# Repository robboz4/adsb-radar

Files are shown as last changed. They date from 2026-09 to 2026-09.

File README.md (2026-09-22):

# ADS-B Radar Display

A live aircraft radar scope for a small round LCD, built from ADS-B data. Runs
on either a Raspberry Pi Zero W or an XIAO ESP32-C3, both driving a 1.28"
GC9A01A round display (240×240, SPI).

## Features

- Live traffic from [adsb.lol](https://adsb.lol), with [adsb.fi](https://adsb.fi)
  as a fallback
- Bearing/distance radar scope centred on a fixed home location, with range
  rings and aircraft markers
- Sweep animation — a rotating arm reveals aircraft as it passes their bearing
- Phosphor-fade rendering — aircraft and labels fade out over time rather
  than disappearing instantly, mimicking an old CRT radar scope
- Two independent implementations sharing the same look and data source, so
  you can run this on whichever board you have on hand

## Hardware

| Platform | Files |
|---|---|
| Raspberry Pi Zero W  | `adsb_radar_core.py`, `adsb_radar_display.py` |
| XIAO ESP32-C3 | `WW11_RADAR-Final.ino` |

Both drive a 1.28" round GC9A01A SPI LCD (240×240).

### Raspberry Pi Zero W

- CircuitPython/displayio via Blinka, using `adafruit-circuitpython-gc9a01a`
  and `fourwire.FourWire`
- `adsb_radar_core.py` handles the adsb.lol/adsb.fi data and bearing/distance
  math; `adsb_radar_display.py` draws the scope
- Refresh is roughly 20 seconds/frame — a limitation of displayio's software
  rendering on the Zero, not the data source
- Run with the `radar` shell alias, or `python3 adsb_radar_display.py`

### XIAO ESP32-C3

- `WW11_RADAR-Final.ino`, built with Arduino_GFX, WiFiClientSecure,
  HTTPClient, and ArduinoJson
- Pin mapping (SDA/SCL labels instead of the Pi's CLK/DIN):

  | Signal | Pin          |
  |--------|--------------|
  | SDA    | D10 / GPIO10 |
  | SCL    | D8 / GPIO8   |
  | DC     | D4 / GPIO6   |
  | CS     | D5 / GPIO7   |
  | RST    | D6 / GPIO21  |

- **Built-in setup portal** — no need to hardcode WiFi credentials or a
  location in the sketch. If no WiFi is configured, the display shows the
  access point details instead of the radar scope. Connect to that access
  point at `192.168.4.1` from a phone, tablet, or computer and enter your
  WiFi network and your latitude/longitude from there.
- **Reset button** — a button on the back panel clears the saved WiFi and
  location settings. Hold it down for 3 seconds while powering the board on,
  then reconnect to `192.168.4.1` to reconfigure.

## Case

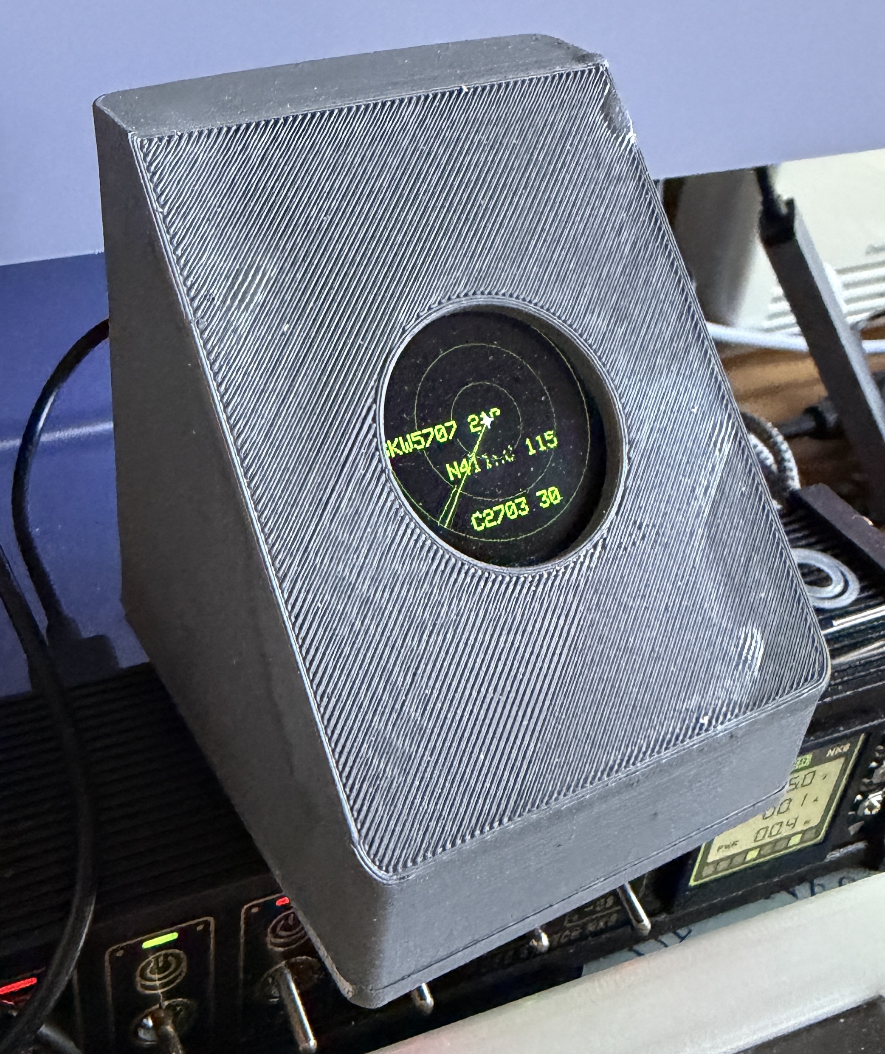
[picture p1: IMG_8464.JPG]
3D-printed case


- `RadarCase-Shell2.stl` and `RadarCase-RearCover.stl` are a 3D-printable
  enclosure sized for the ESP32-C3 build: sloped display face, corner mounting
  bosses for M3 heat-set inserts, and a 32 mm through-hole with internal
  guide posts that the display slides into from the top
- The rear cover includes a cutout for the reset button used to clear WiFi/
  location settings
- A matching Raspberry Pi enclosure hasn't been designed yet

## Configuration

- **ESP32-C3:** no code editing needed — WiFi and location are set through
  the `192.168.4.1` setup portal described above.
- **Raspberry Pi:** set your location directly in `adsb_radar_core.py`:

  ```python
  HOME_LAT = 0.00
  HOME_LON = 0.00cd 
  
  ```

## Roadmap

- Traffic filtering by commercial / private / military category
- A 3D-printable case for the Raspberry Pi build

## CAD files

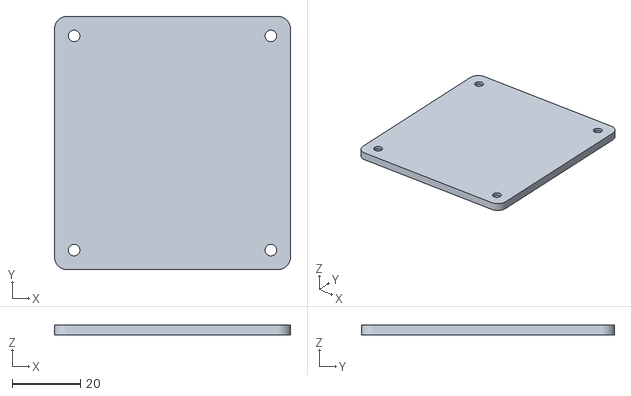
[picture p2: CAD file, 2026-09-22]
RadarCase-RearCover.stl
69.2 x 74.3 x 3.00

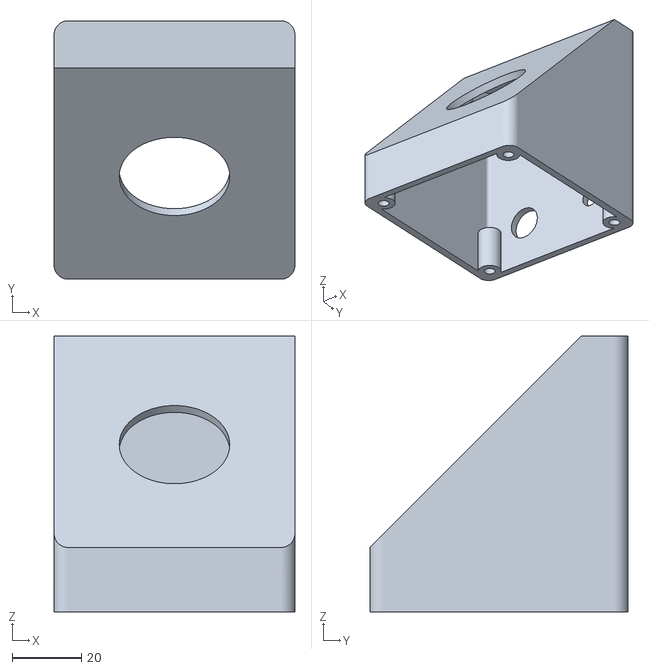
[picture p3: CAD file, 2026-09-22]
RadarCase-Shell2.stl
69.7 x 74.8 x 79.9

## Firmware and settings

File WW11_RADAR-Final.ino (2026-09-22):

// ============================================================
// WW-II Phosphor Radar - XIAO ESP32-C3 + GC9A01 Round LCD
// ============================================================
// Authentic WWII PPI radar simulation with captive portal
// configuration -- no recompile needed to change settings.
//
// FIRST TIME SETUP:
//   1. Power on the device
//   2. Connect your phone/laptop to WiFi network "RadarSetup"
//   3. A config page will open automatically (captive portal)
//   4. Enter your WiFi credentials, latitude, longitude, radius
//   5. Hit Save -- device reboots and starts radar mode
//
// RECONFIGURE:
//   Hold external button on D7 (GPIO20) for 3 seconds at
//   power-on to reset settings and re-enter setup mode
//
// Wiring (XIAO ESP32-C3):
//   Display VCC → 3.3V
//   Display GND → GND
//   Display SCL → D8  (GPIO8)
//   Display SDA → D10 (GPIO10)
//   Display DC  → D4  (GPIO6)
//   Display CS  → D5  (GPIO7)
//   Display RST → D6  (GPIO21)
//   Reset button → D7 (GPIO20) to GND
//
// Libraries required:
//   - GFX Library for Arduino (moononournation)
//   - WiFiManager (tzapu)
//   - ArduinoJson (Benoit Blanchon)
// ============================================================

#include <Arduino_GFX_Library.h>
#include <WiFi.h>
#include <WiFiClientSecure.h>
#include <WiFiManager.h>
#include <HTTPClient.h>
#include <ArduinoJson.h>
#include <Preferences.h>
#include <math.h>

// ============================================================
// DISPLAY PINS (XIAO ESP32-C3)
// ============================================================
#define TFT_CS   7    // D5
#define TFT_DC   6    // D4
#define TFT_RST  21   // D6
#define TFT_MOSI 10   // D10
#define TFT_SCLK 8    // D8

// External reset button (momentary switch to GND)
#define BOOT_PIN 20   // D7

// ============================================================
// COLOURS (RGB565)
// ============================================================
#define COLOR_BG      0x0020  // near-black green background
#define COLOR_RING    0x02A0  // static ring green (never fades)
#define COLOR_CENTER  0xFFFF  // white center marker (never fades)
#define COLOR_SWEEP   0x47E6  // bright sweep arm green
#define BLACK         0x0000
#define RED           0xF800
#define WHITE         0xFFFF

// Phosphor brightness steps: full bright → dim → background
// 9 steps for smooth staircase decay over FADE_MS
const uint16_t PHOSPHOR[] = {
    0x07E0,   // step 0: full bright green (100%)
    0x06E0,   // step 1: ~87%
    0x05E0,   // step 2: ~75%
    0x04E0,   // step 3: ~62%
    0x03E0,   // step 4: ~50%
    0x02E0,   // step 5: ~37%
    0x01E0,   // step 6: ~25%
    0x00E0,   // step 7: very dim
    0x0020    // step 8: background (gone)
};
const int PHOSPHOR_STEPS = 9;

// ============================================================
// RADAR GEOMETRY
// ============================================================
#define SCREEN_W   240
#define SCREEN_H   240
#define CENTER_X   120
#define CENTER_Y   120
#define MAX_RADIUS 108  // outermost ring radius in pixels
#define RING_COUNT 3    // number of range rings
#define MAX_AC     30   // max aircraft to track
#define DOT_SIZE   3    // overlap marker dot radius

// ============================================================
// CONFIGURATION (loaded from flash at startup)
// ============================================================
float        HOME_LAT  = 38.80579;   // default fallback
float        HOME_LON  = -121.11277; // default fallback
int          RADIUS_NM = 10;         // default fallback

const unsigned long SWEEP_MS = 2000; // sweep arm duration (ms)
const unsigned long FADE_MS  = 8000; // total fade duration (ms)

// ============================================================
// AIRCRAFT DATA STRUCTURE
// ============================================================
struct Aircraft {
    float bearing_deg;  // bearing from home (0=North, clockwise)
    int   x, y;         // screen pixel coordinates
    int   alt_ft;       // altitude in feet
    char  callsign[10]; // callsign or tail number
};

Aircraft ac_list[MAX_AC];
int      ac_count = 0;

// Label bounding boxes for overlap detection
struct LabelBox {
    int x, y, w, h;
};
LabelBox drawn_boxes[MAX_AC];
int      box_count = 0;

// ============================================================
// GFX + PREFERENCES
// ============================================================
Arduino_DataBus *bus = new Arduino_ESP32SPI(
    TFT_DC, TFT_CS, TFT_SCLK, TFT_MOSI, GFX_NOT_DEFINED
);
Arduino_GFX *gfx = new Arduino_GC9A01(bus, TFT_RST, 0, true);

Preferences prefs;

// ============================================================
// MATH HELPERS
// ============================================================

// Great-circle bearing from point 1 to point 2
// Returns 0-360 degrees (0=North, clockwise)
float calc_bearing(float lat1, float lon1, float lat2, float lon2) {
    float phi1 = radians(lat1), phi2 = radians(lat2);
    float dl   = radians(lon2 - lon1);
    float y    = sin(dl) * cos(phi2);
    float x    = cos(phi1)*sin(phi2) - sin(phi1)*cos(phi2)*cos(dl);
    float brng = fmod(degrees(atan2(y, x)) + 360.0, 360.0);
    if (brng >= 360.0f) brng = 0.0f;
    return brng;
}

// Haversine distance between two points in nautical miles
float calc_distance_nm(float lat1, float lon1, float lat2, float lon2) {
    const float R = 3440.065;
    float dphi = radians(lat2 - lat1);
    float dl   = radians(lon2 - lon1);
    float phi1 = radians(lat1), phi2 = radians(lat2);
    float a = sin(dphi/2)*sin(dphi/2) +
              cos(phi1)*cos(phi2)*sin(dl/2)*sin(dl/2);
    return R * 2 * atan2(sqrt(a), sqrt(1-a));
}

// Convert bearing + distance to screen x,y pixel coordinates
void polar_to_xy(float brng, float dist_nm, int &x, int &y) {
    float scale = min(dist_nm / (float)RADIUS_NM, 1.0f);
    float r     = scale * MAX_RADIUS;
    float a     = radians(brng);
    x = CENTER_X + (int)(r * sin(a));
    y = CENTER_Y - (int)(r * cos(a));
}

// Sort aircraft by bearing (insertion sort)
void sort_by_bearing() {
    for (int i = 1; i < ac_count; i++) {
        Aircraft key = ac_list[i];
        int j = i - 1;
        while (j >= 0 && ac_list[j].bearing_deg > key.bearing_deg) {
            ac_list[j+1] = ac_list[j];
            j--;
        }
        ac_list[j+1] = key;
    }
}

// ============================================================
// OVERLAP DETECTION
// Check if a proposed label rectangle overlaps any already
// drawn label. Returns true if overlap detected.
// ============================================================
bool overlaps_existing(int lx, int ly, int lw, int lh) {
    for (int i = 0; i < box_count; i++) {
        if (lx < drawn_boxes[i].x + drawn_boxes[i].w &&
            lx + lw > drawn_boxes[i].x &&
            ly < drawn_boxes[i].y + drawn_boxes[i].h &&
            ly + lh > drawn_boxes[i].y) {
            return true;
        }
    }
    return false;
}

// ============================================================
// DRAWING FUNCTIONS
// ============================================================

// Draw center crosshair marker (your location)
void draw_center_marker() {
    gfx->fillCircle(CENTER_X, CENTER_Y, 3, COLOR_CENTER);
    gfx->drawLine(CENTER_X-6, CENTER_Y, CENTER_X+6, CENTER_Y, COLOR_CENTER);
    gfx->drawLine(CENTER_X, CENTER_Y-6, CENTER_X, CENTER_Y+6, COLOR_CENTER);
}

// Draw permanent static background -- rings never fade,
// simulating etched glass overlay on real WWII radar scopes
void draw_static_scene() {
    gfx->fillScreen(COLOR_BG);
    for (int i = 1; i <= RING_COUNT; i++) {
        int r = MAX_RADIUS * i / RING_COUNT;
        gfx->drawCircle(CENTER_X, CENTER_Y, r, COLOR_RING);
    }
    gfx->drawCircle(CENTER_X, CENTER_Y, MAX_RADIUS, COLOR_RING);
    draw_center_marker();
}

// Draw one aircraft label at a given phosphor brightness.
// If label would overlap an existing one, draw a small dot
// instead so the aircraft position is still visible.
void draw_one_aircraft(int idx, uint16_t colour) {
    Aircraft &ac = ac_list[idx];

    int  alt_k = (int)(ac.alt_ft / 100);
    char label[16];
    snprintf(label, sizeof(label), "%s %d", ac.callsign, alt_k);

    int label_len = strlen(label);
    int label_w   = label_len * 12;  // 12px per char at textSize 2
    int label_h   = 16;              // 16px tall at textSize 2

    // Position label to right of dot by default,
    // flip left if it would overflow right edge
    int lx = ac.x + 6;
    if (lx + label_w > SCREEN_W - 2) lx = ac.x - label_w - 6;
    if (lx < 2) lx = 2;

    int ly = ac.y - 4;
    if (ly < label_h)                 ly = ac.y + 6;
    if (ly + label_h > SCREEN_H - 2) ly = SCREEN_H - label_h - 2;

    if (overlaps_existing(lx, ly, label_w, label_h)) {
        // Overlap detected -- draw small dot instead of label
        gfx->fillCircle(ac.x, ac.y, DOT_SIZE, colour);
        Serial.printf("  [overlap] %s -- dot only\n", ac.callsign);
    } else {
        // No overlap -- record bounding box and draw full label
        drawn_boxes[box_count++] = {lx, ly, label_w, label_h};
        gfx->fillRect(lx, ly, label_w + 4, label_h, COLOR_BG);
        gfx->setTextWrap(false);
        gfx->setTextSize(2);
        int cx = lx;
        for (int i = 0; i < label_len; i++) {
            gfx->drawChar(cx, ly, (unsigned char)label[i], colour, COLOR_BG);
            cx += 12;
        }
    }
}

// Draw all aircraft at a given brightness level
void draw_all_aircraft(uint16_t colour) {
    box_count = 0;  // reset overlap tracking for this redraw
    for (int i = 0; i < ac_count; i++) {
        draw_one_aircraft(i, colour);
    }
}

// Draw sweep arm line from center to edge at given angle
void draw_sweep_arm(float angle_deg, uint16_t colour) {
    float a  = radians(angle_deg);
    int   x2 = CENTER_X + (int)(MAX_RADIUS * sin(a));
    int   y2 = CENTER_Y - (int)(MAX_RADIUS * cos(a));
    gfx->drawLine(CENTER_X, CENTER_Y, x2, y2, colour);
}

// Draw status line at top of screen
void draw_status(int count, bool wifi_ok) {
    gfx->fillRect(0, 0, SCREEN_W, 14, COLOR_BG);
    gfx->setTextSize(1);
    gfx->setTextColor(PHOSPHOR[0], COLOR_BG);
    gfx->setCursor(10, 3);
    if (!wifi_ok) {
        gfx->print("No WiFi");
    } else {
        gfx->print(count);
        gfx->print(" ac  ");
        gfx->print(RADIUS_NM);
        gfx->print("nm");
    }
}

// Display a centered message -- used during WiFi setup
void show_message(const char* line1, const char* line2 = nullptr,
                  uint16_t colour = WHITE) {
    gfx->fillScreen(BLACK);
    for (int i = 1; i <= RING_COUNT; i++) {
        int r = MAX_RADIUS * i / RING_COUNT;
        gfx->drawCircle(CENTER_X, CENTER_Y, r, 0x0060);
    }
    gfx->setTextWrap(true);
    gfx->setTextSize(1);
    gfx->setTextColor(colour, BLACK);
    if (line2 == nullptr) {
        gfx->setCursor(10, 115);
        gfx->print(line1);
    } else {
        gfx->setCursor(10, 105);
        gfx->print(line1);
        gfx->setCursor(10, 120);
        gfx->print(line2);
    }
}

// ============================================================
// RADAR SWEEP ANIMATION
// Arm rotates 0->360 over SWEEP_MS revealing aircraft as it
// passes their bearing. Uses surgical erase (previous arm line
// only) to prevent flicker on already-revealed labels.
// ============================================================
void radar_sweep() {
    sort_by_bearing();

    int next_ac = 0;
    box_count = 0;  // reset overlap tracking for new sweep
    unsigned long sweep_start = millis();
    const int STEPS = 180;  // 2 degrees per step

    // Full clean wipe before sweep -- clears previous cycle's
    // faded aircraft. Double fillScreen ensures complete clear.
    gfx->fillScreen(COLOR_BG);
    gfx->fillScreen(COLOR_BG);
    for (int i = 1; i <= RING_COUNT; i++) {
        int r = MAX_RADIUS * i / RING_COUNT;
        gfx->drawCircle(CENTER_X, CENTER_Y, r, COLOR_RING);
    }
    gfx->drawCircle(CENTER_X, CENTER_Y, MAX_RADIUS, COLOR_RING);
    draw_center_marker();

    float prev_angle = -1;

    for (int step = 0; step <= STEPS; step++) {
        float angle = 360.0f * step / STEPS;

        // Surgical erase: repaint previous arm line with background,
        // then restore ring pixels the arm erased
        if (prev_angle >= 0) {
            draw_sweep_arm(prev_angle, COLOR_BG);
            for (int i = 1; i <= RING_COUNT; i++) {
                int r = MAX_RADIUS * i / RING_COUNT;
                float pa = radians(prev_angle);
                int rx = CENTER_X + (int)(r * sin(pa));
                int ry = CENTER_Y - (int)(r * cos(pa));
                gfx->drawPixel(rx, ry, COLOR_RING);
            }
            float pa = radians(prev_angle);
            int rx = CENTER_X + (int)(MAX_RADIUS * sin(pa));
            int ry = CENTER_Y - (int)(MAX_RADIUS * cos(pa));
            gfx->drawPixel(rx, ry, COLOR_RING);
        }

        // Reveal aircraft whose bearing the sweep arm has reached.
        // angle > 0.5 guard prevents reveals before arm has moved.
        while (next_ac < ac_count &&
               ac_list[next_ac].bearing_deg <= angle &&
               angle > 0.5f) {
            Serial.printf("Revealing %s at sweep angle=%.1f brng=%.1f\n",
                ac_list[next_ac].callsign, angle,
                ac_list[next_ac].bearing_deg);
            draw_one_aircraft(next_ac, PHOSPHOR[0]);
            next_ac++;
        }

        // Draw sweep arm at current angle
        draw_sweep_arm(angle, COLOR_SWEEP);
        draw_center_marker();
        prev_angle = angle;

        // Pace sweep to SWEEP_MS total duration
        unsigned long elapsed  = millis() - sweep_start;
        unsigned long expected = (unsigned long)(SWEEP_MS * step / STEPS);
        if (expected > elapsed) delay(expected - elapsed);
    }

    // Clean up: erase final arm, restore outer ring, reveal
    // any remaining aircraft (edge case: bearing near 360)
    draw_sweep_arm(360.0f, COLOR_BG);
    gfx->drawCircle(CENTER_X, CENTER_Y, MAX_RADIUS, COLOR_RING);
    draw_center_marker();
    while (next_ac < ac_count) {
        draw_one_aircraft(next_ac, PHOSPHOR[0]);
        next_ac++;
    }
}

// ============================================================
// PHOSPHOR FADE
// Steps through 9 brightness levels over FADE_MS total.
// Each step: wipe screen, redraw rings (permanent), redraw
// aircraft at next dimmer colour level.
// Rings and center marker never fade -- etched glass effect.
// ============================================================
void phosphor_fade() {
    unsigned long step_ms = FADE_MS / (PHOSPHOR_STEPS - 1);
    // 8000ms / 8 steps = 1000ms per step

    for (int step = 1; step < PHOSPHOR_STEPS; step++) {
        delay(step_ms);

        gfx->fillScreen(COLOR_BG);

        // Rings and center always redrawn solid -- never fade
        for (int i = 1; i <= RING_COUNT; i++) {
            int r = MAX_RADIUS * i / RING_COUNT;
            gfx->drawCircle(CENTER_X, CENTER_Y, r, COLOR_RING);
        }
        gfx->drawCircle(CENTER_X, CENTER_Y, MAX_RADIUS, COLOR_RING);
        draw_center_marker();

        // Redraw aircraft at current fade level
        // Skip last step -- background colour, nothing to draw
        if (step < PHOSPHOR_STEPS - 1) {
            draw_all_aircraft(PHOSPHOR[step]);
        }

        draw_status(ac_count, WiFi.status() == WL_CONNECTED);
    }
}

// ============================================================
// ADS-B DATA FETCH
// Tries adsb.lol first, falls back to adsb.fi on failure.
// Uses getString() to avoid IncompleteInput parse errors.
// ============================================================
int fetch_aircraft() {
    if (WiFi.status() != WL_CONNECTED) return -1;

    const char* api_urls[2] = {
        "https://api.adsb.lol/v2/point/%.4f/%.4f/%d",
        "https://opendata.adsb.fi/api/v2/point/%.4f/%.4f/%d"
    };

    String payload  = "";
    bool   got_data = false;

    for (int u = 0; u < 2 && !got_data; u++) {
        char url[128];
        snprintf(url, sizeof(url), api_urls[u],
                 HOME_LAT, HOME_LON, RADIUS_NM);
        Serial.printf("Trying: %s\n", url);

        WiFiClientSecure client;
        client.setInsecure();
        HTTPClient http;
        http.begin(client, url);
        http.setTimeout(8000);
        int httpCode = http.GET();

        if (httpCode == 200) {
            payload  = http.getString();
            got_data = true;
            Serial.println("Fetch OK");
        } else {
            Serial.printf("HTTP %d, trying next...\n", httpCode);
        }
        http.end();
    }

    if (!got_data) return -1;

    // Filter to only fields we need (saves RAM)
    DynamicJsonDocument filter(200);
    JsonObject ac_filter = filter["ac"].createNestedObject();
    ac_filter["lat"]      = true;
    ac_filter["lon"]      = true;
    ac_filter["alt_baro"] = true;
    ac_filter["flight"]   = true;
    ac_filter["hex"]      = true;

    DynamicJsonDocument doc(24576);  // 24KB buffer
    DeserializationError err = deserializeJson(doc, payload,
        DeserializationOption::Filter(filter));

    if (err) {
        Serial.printf("JSON error: %s\n", err.c_str());
        return -1;
    }

    JsonArray aircraft = doc["ac"];
    ac_count = 0;

    for (JsonObject ac : aircraft) {
        if (ac_count >= MAX_AC) break;

        float ac_lat = ac["lat"] | -999.0f;
        float ac_lon = ac["lon"] | -999.0f;
        if (ac_lat == -999.0f || ac_lon == -999.0f) continue;

        float dist = calc_distance_nm(HOME_LAT, HOME_LON, ac_lat, ac_lon);
        if (dist > RADIUS_NM) continue;

        int alt_ft = 0;
        if (ac["alt_baro"].is<int>()) alt_ft = ac["alt_baro"].as<int>();

        const char* cs_raw = ac["flight"] | ac["hex"] | "?";
        memset(ac_list[ac_count].callsign, 0,
               sizeof(ac_list[0].callsign));
        strncpy(ac_list[ac_count].callsign, cs_raw,
                sizeof(ac_list[0].callsign) - 1);

        // Trim trailing whitespace from callsign
        for (int i = strlen(ac_list[ac_count].callsign)-1;
             i >= 0 && (ac_list[ac_count].callsign[i] == ' '  ||
                        ac_list[ac_count].callsign[i] == '\t' ||
                        ac_list[ac_count].callsign[i] == '\r' ||
                        ac_list[ac_count].callsign[i] == '\n'); i--)
            ac_list[ac_count].callsign[i] = '\0';

        ac_list[ac_count].alt_ft      = alt_ft;
        ac_list[ac_count].bearing_deg = calc_bearing(
            HOME_LAT, HOME_LON, ac_lat, ac_lon);
        polar_to_xy(ac_list[ac_count].bearing_deg, dist,
                    ac_list[ac_count].x, ac_list[ac_count].y);

        Serial.printf("  [%d] %s alt=%d brng=%.0f dist=%.1fnm\n",
            ac_count, ac_list[ac_count].callsign,
            alt_ft, ac_list[ac_count].bearing_deg, dist);

        ac_count++;
    }

    return 0;
}

// ============================================================
// SETTINGS: SAVE / LOAD / RESET (ESP32 flash via Preferences)
// ============================================================
void save_settings(float lat, float lon, int nm) {
    prefs.begin("radar", false);
    prefs.putFloat("lat", lat);
    prefs.putFloat("lon", lon);
    prefs.putInt("nm",  nm);
    prefs.putBool("configured", true);
    prefs.end();
    Serial.printf("Settings saved: lat=%.5f lon=%.5f nm=%d\n",
                  lat, lon, nm);
}

bool load_settings() {
    prefs.begin("radar", true);
    bool configured = prefs.getBool("configured", false);
    if (configured) {
        HOME_LAT  = prefs.getFloat("lat", HOME_LAT);
        HOME_LON  = prefs.getFloat("lon", HOME_LON);
        RADIUS_NM = prefs.getInt("nm",   RADIUS_NM);
    }
    prefs.end();
    Serial.printf("Settings loaded: lat=%.5f lon=%.5f nm=%d\n",
                  HOME_LAT, HOME_LON, RADIUS_NM);
    return configured;
}

void reset_settings() {
    prefs.begin("radar", false);
    prefs.clear();
    prefs.end();
    Serial.println("Settings cleared.");
}
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
void loop() {
    Serial.println("\n--- New cycle ---");

    int result = fetch_aircraft();
    if (result != 0) {
        Serial.println("Fetch failed, using last known data.");
    }

    radar_sweep();
    draw_status(ac_count, WiFi.status() == WL_CONNECTED);
    phosphor_fade();
}

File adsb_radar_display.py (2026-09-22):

"""
ADS-B Aircraft Radar for the 1.28" round GC9A01A LCD on Raspberry Pi.

Draws a radar-scope view: your location at the center, range rings,
and aircraft positioned by real-time bearing/distance. Each aircraft
is shown as a single text label (an asterisk marker + callsign +
altitude) -- marker and text are baked into one Label object so they
always appear together, with no possibility of one updating before
the other during a slow refresh. Refreshes periodically from adsb.lol.

Design note: the background, range rings, and center marker are drawn
directly into ONE bitmap that is fully repainted (cleared + redrawn)
every cycle, and each refresh cycle first wipes to a blank scene before
drawing the new one. This avoids ghosting/trails that occur when many
small separate sprites or labels are added/removed individually --
Blinka's displayio dirty-region tracking can miss repainting the exact
old footprint of a removed sprite. A full wipe + full repaint guarantees
every pixel is touched and no stale frame is ever partially visible.

Run with: python3 adsb_radar_display.py
Stop with: Ctrl+C
"""

import time
import math
import board
import busio
import displayio
import digitalio
import terminalio
import fourwire
from adafruit_display_text import label
from adafruit_gc9a01a import GC9A01A

import adsb_radar_core as core

# ---------------- CONFIG ----------------
CENTER = (120, 120)
MAX_RADIUS_PX = 110       # outermost ring radius in pixels
RING_COUNT = 3            # number of range rings (e.g. 3 rings = thirds of RADIUS_NM)
REFRESH_SECONDS = 10      # how often to re-query the API (seconds)
MAX_AIRCRAFT_LABELS = 12  # avoid clutter if many aircraft are in range

COLOR_BG = 0x001A00        # near-black green tint (classic radar look)
COLOR_RING = 0x00AA00      # green range rings
COLOR_AIRCRAFT = 0xFFAA00  # amber - used for aircraft marker+callsign labels
COLOR_TEXT = 0x00FF00      # bright green labels
COLOR_CENTER = 0xFFFFFF    # white center marker

# Palette indices (single shared palette for the whole scene bitmap)
IDX_BG = 0
IDX_RING = 1
IDX_AIRCRAFT = 2
IDX_CENTER = 3

# ---------------- DISPLAY SETUP ----------------
displayio.release_displays()

spi = busio.SPI(clock=board.SCLK, MOSI=board.MOSI)
tft_cs = board.CE0
tft_dc = board.D25
tft_rst = board.D27

bl = digitalio.DigitalInOut(board.D18)
bl.direction = digitalio.Direction.OUTPUT
bl.value = True

display_bus = fourwire.FourWire(spi, command=tft_dc, chip_select=tft_cs,
                                 reset=tft_rst, baudrate=24000000)
display = GC9A01A(display_bus, width=240, height=240)
display.auto_refresh = False  # we control exactly when to redraw

# ---------------- SCENE: one bitmap for background + rings + dots ----------------
main_group = displayio.Group()
display.root_group = main_group

scene_bitmap = displayio.Bitmap(240, 240, 4)  # 4 palette entries
scene_palette = displayio.Palette(4)
scene_palette[IDX_BG] = COLOR_BG
scene_palette[IDX_RING] = COLOR_RING
scene_palette[IDX_AIRCRAFT] = COLOR_AIRCRAFT
scene_palette[IDX_CENTER] = COLOR_CENTER

scene_sprite = displayio.TileGrid(scene_bitmap, pixel_shader=scene_palette, x=0, y=0)
main_group.append(scene_sprite)

# Status text (top of screen) - shows last update / aircraft count.
# Kept as a separate Label since it sits over a fixed, simple background
# area; if it ever ghosts too, move it into the bitmap as plain pixels.
status_label = label.Label(terminalio.FONT, text="Starting...", color=COLOR_TEXT,
                            x=60, y=18, scale=1)
main_group.append(status_label)

# Aircraft text labels live in their own group, fully rebuilt each cycle.
label_group = displayio.Group()
main_group.append(label_group)


def fill_background(bitmap):
    """Reset every pixel in the scene bitmap back to background color."""
    bitmap.fill(IDX_BG)


def draw_ring(bitmap, cx, cy, radius, palette_index):
    """Plot a circle outline directly into the bitmap (no sprites)."""
    steps = max(72, int(radius * 4))
    for i in range(steps):
        angle = 2 * math.pi * i / steps
        x = int(cx + radius * math.cos(angle))
        y = int(cy + radius * math.sin(angle))
        if 0 <= x < bitmap.width and 0 <= y < bitmap.height:
            bitmap[x, y] = palette_index


def draw_center_marker(bitmap, cx, cy, palette_index, size=2):
    for dx in range(-size, size + 1):
        for dy in range(-size, size + 1):
            x, y = cx + dx, cy + dy
            if 0 <= x < bitmap.width and 0 <= y < bitmap.height:
                bitmap[x, y] = palette_index


def redraw_scene():
    """Fully repaint background, range rings, and center marker.

    Aircraft are NOT drawn here -- they're rendered entirely as text
    labels (marker + callsign + altitude in one Label) by rebuild_labels().
    """
    fill_background(scene_bitmap)

    for i in range(1, RING_COUNT + 1):
        r = int(MAX_RADIUS_PX * i / RING_COUNT)
        draw_ring(scene_bitmap, CENTER[0], CENTER[1], r, IDX_RING)

    draw_center_marker(scene_bitmap, CENTER[0], CENTER[1], IDX_CENTER)


def rebuild_labels(points):
    """Clear and rebuild the text label group for aircraft markers + callsign/alt.

    The marker (an asterisk) is prepended directly to each label's text,
    so the position-marker and the callsign/altitude text are a single
    Label object -- one atomic unit on screen. This avoids the marker and
    text becoming visible at different moments during a slow refresh.
    """
    while len(label_group) > 0:
        label_group.pop()

    for idx, p in enumerate(points[:MAX_AIRCRAFT_LABELS]):
        x, y = p["x"], p["y"]
        alt_k = round(p["alt_ft"] / 100)  # e.g. 350 = 35,000 ft
        text = f"*{p['callsign']} {alt_k}"
        txt_label = label.Label(
            terminalio.FONT, text=text, color=COLOR_AIRCRAFT,
            x=min(max(0, x - 5), 240 - len(text) * 6),
            y=min(max(8, y), 232), scale=1,
        )
        label_group.append(txt_label)


# Initial static draw (no aircraft labels yet)
redraw_scene()
display.refresh()
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
